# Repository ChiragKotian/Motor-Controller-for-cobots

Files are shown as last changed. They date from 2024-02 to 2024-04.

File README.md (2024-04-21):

# Motor-Controller-for-cobots

## Check out presentation.pdf(https://github.com/ChiragKotian/Motor-Controller-for-cobots/blob/main/presentation.pdf) for complete details

### _NOTE_: The final circuit shown in the schematics doesn't contain any protection for the inductive nature of the motor. Be sure to implement them before using this circuit or else you might end-up damaging your controller. 

## Credits

_This project was entirely done by Chirag Kotian (https://github.com/ChiragKotian) as a 'Pre-internship assignment' for PrimaInnotech. If you want to use my work, you are free to do so; don't forget to mention my GitHub page: https://github.com/ChiragKotian._

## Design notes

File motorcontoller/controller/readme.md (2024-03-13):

https://www.integrasources.com/blog/bldc-motor-controller-design-principles/

A typical BLDC motor controller has a half-bridge or half-H bridge circuit. Unlike an H bridge, this circuit configuration has only two switches - one high-side and one low-side transistor.

Typically, a sinusoidal brushless motor controller circuit uses pulse-width modulation (PWM). It helps regulate the current injected into the rotor’s windings and run the commutation process more smoothly and efficiently. This applies especially to closed-loop controllers that get feedback on the output signal and adjust the input power by varying the duty cycle.

When designing a BLDC motor controller, engineers can use different current switching, including trapezoidal and sinusoidal commutation. The names relate to the signal waveforms. 

The trapezoidal commutation allows two windings out of three to stay energized simultaneously. In the sinusoidal approach, the phase shift complies with the law of sines, so current switching between the phases becomes smoother. 

((Cant do SPI as D10,D11 PWM) between hall and mcu use I2C

https://ams.com/documents/20143/36005/AS5147_DS000307_3-00.pdf)

Use other Mag encoder
ams AS5048B

magnetic encoder, no moving parts

- 0.02197 deg resolution
- 14 bit resolution

-In applications where a sensored FOC scheme is preferred, Infineon’s XENSIV™ TLE5012 magnetic angle sensors with 0.01° resolution can be used 
for precise positioning. (SPI)

Compare with 



Similar Vdsmax and Ids max

80kHz



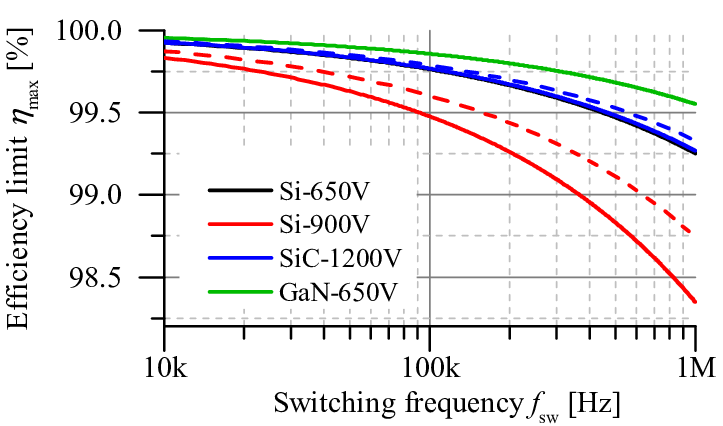
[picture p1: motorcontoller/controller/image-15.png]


We can use 200kHz similar switching loses

150% increase in frequency

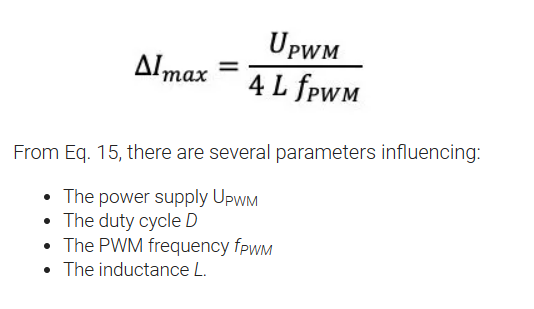
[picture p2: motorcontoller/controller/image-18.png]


60% reduction in ripple currrent

https://www.controleng.com/articles/understanding-the-effect-of-pwm-when-controlling-a-brushless-dc-motor/

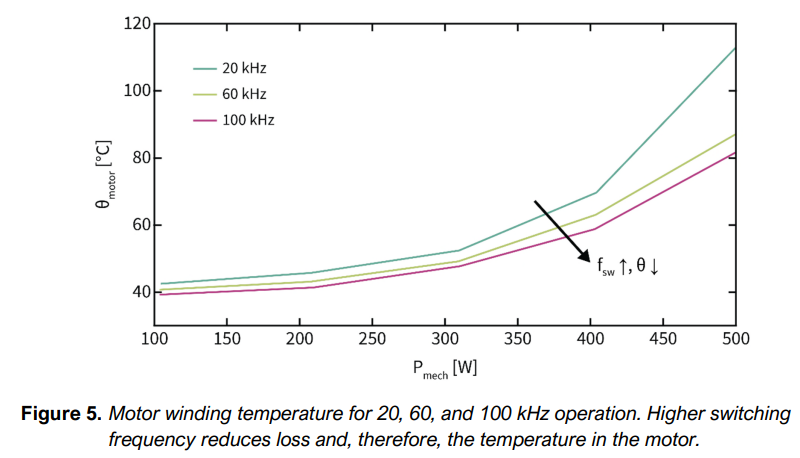
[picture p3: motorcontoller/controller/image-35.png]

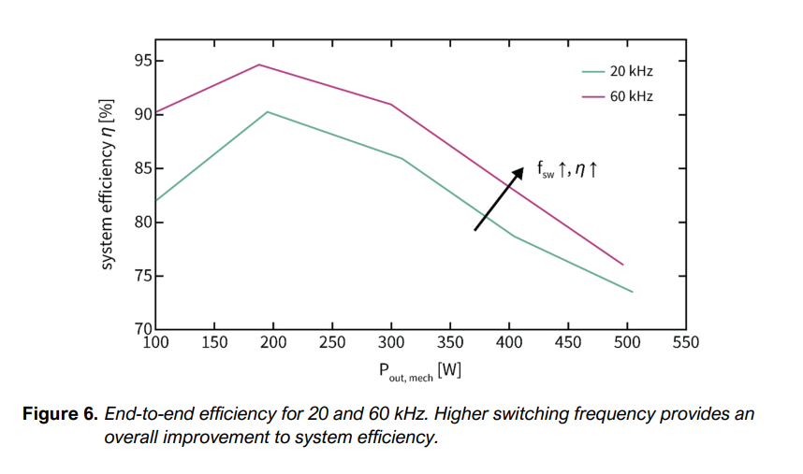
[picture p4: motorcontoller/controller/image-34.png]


Maerz, Martin & Heckel, Thomas & Rettner, Cornelius. (2015). Fundamental Efficiency Limits in Power Electronic Systems. 10.1109/INTLEC.2015.7572399. 

4 GaNs

-IGO60R070D1 
-IGOT60R070D1 
-IGLD60R070D1 
-IGT60R070D1 

we will use IGT60R070D1

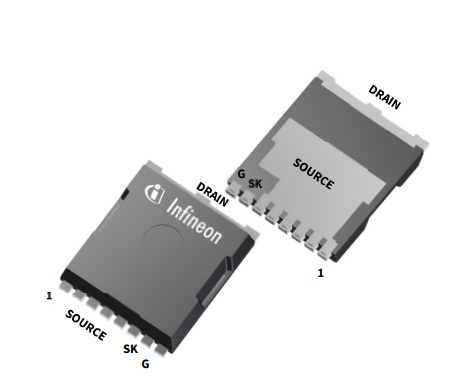
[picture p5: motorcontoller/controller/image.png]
![alt text](image-1.png)


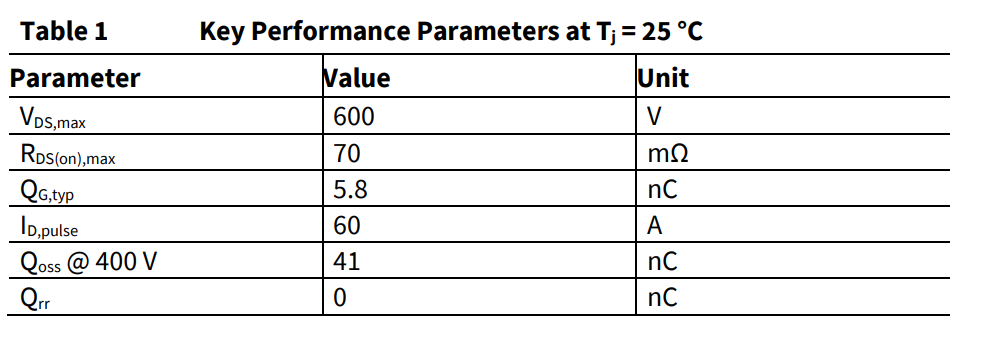
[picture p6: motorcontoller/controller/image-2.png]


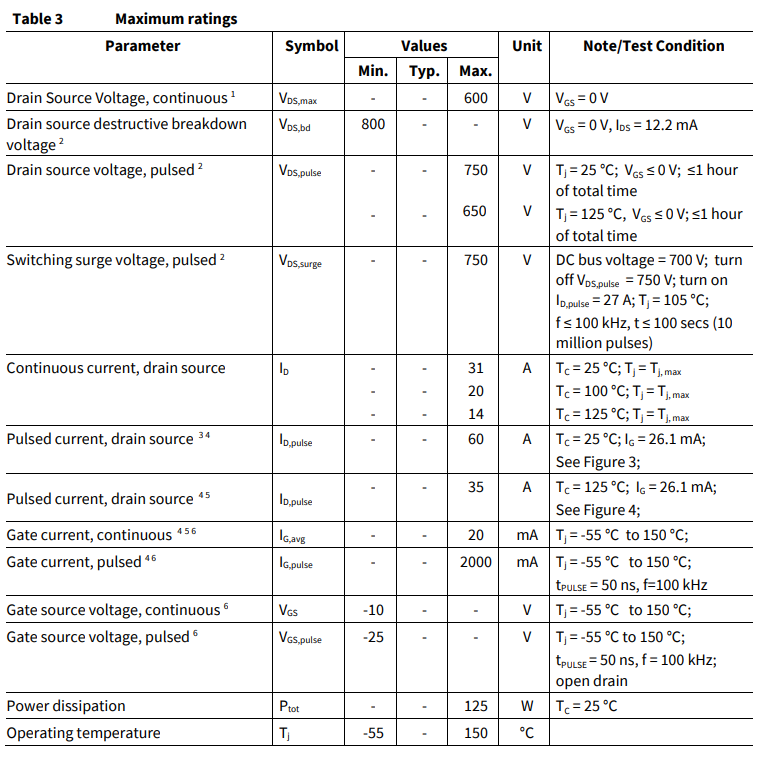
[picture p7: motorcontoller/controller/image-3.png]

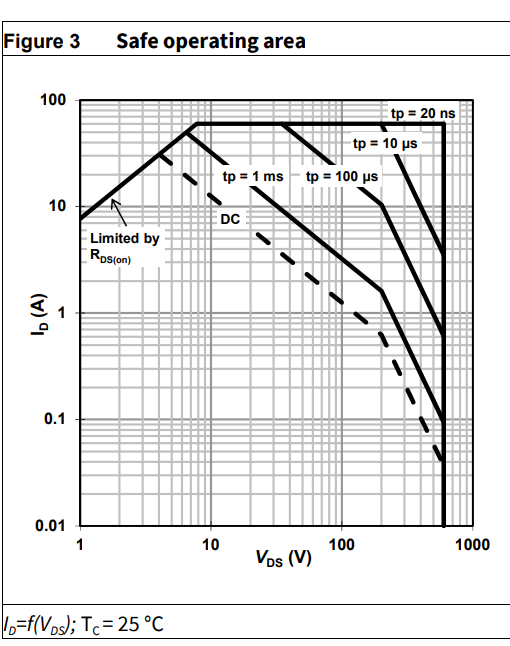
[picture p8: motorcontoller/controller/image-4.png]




Vgs = 5

turn on delay = 10ns
turn off delay = 14ns

GaN driver-
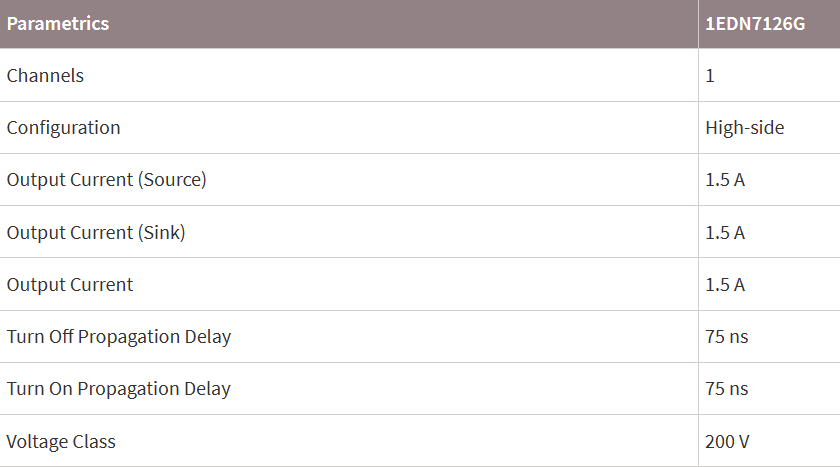
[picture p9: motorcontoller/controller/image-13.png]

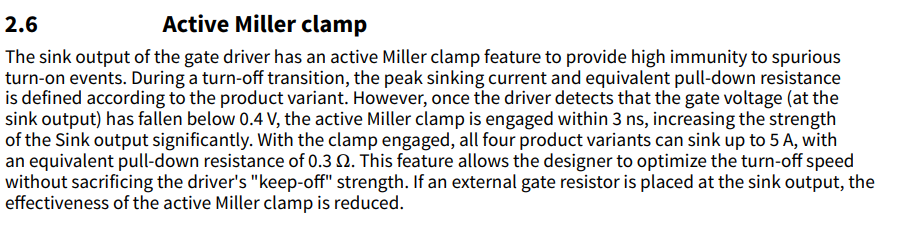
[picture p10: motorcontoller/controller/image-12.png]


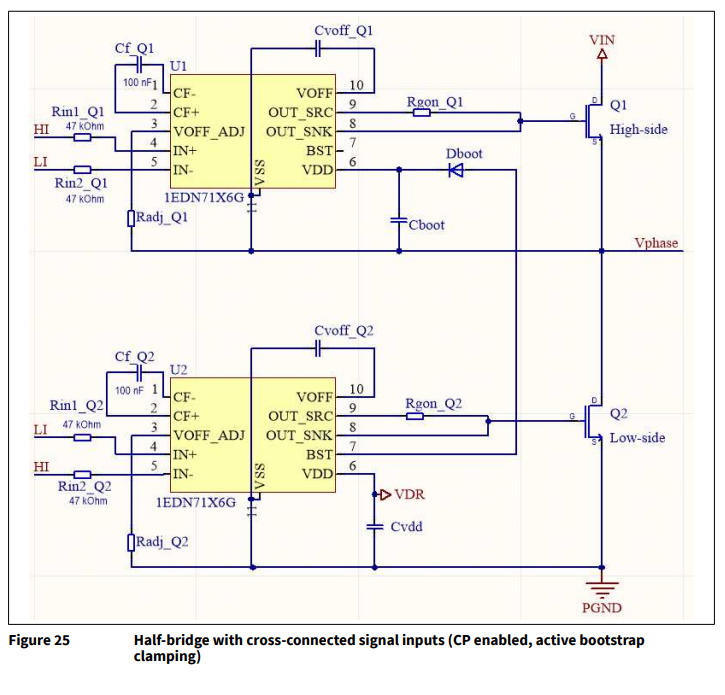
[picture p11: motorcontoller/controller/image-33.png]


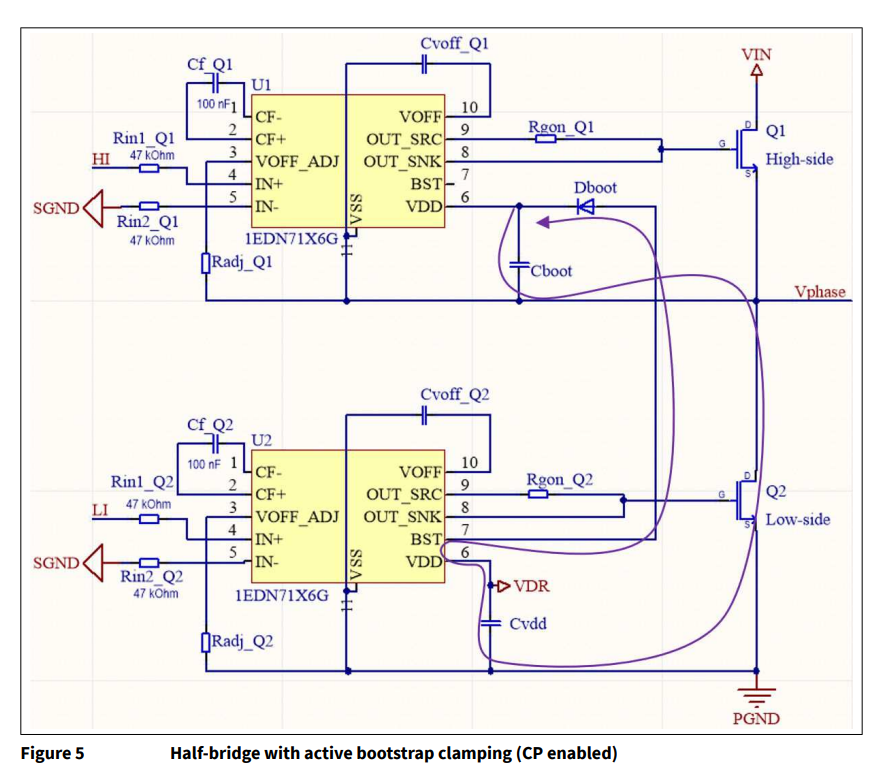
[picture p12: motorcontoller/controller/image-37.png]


Turn on, off  propagation delay= 75ns
impulse blanking time = 40ns(min time pulse on)

A gate driver is a power amplifier that accepts a low power input from a controller IC and produces the appropriate high current gate drive for a power device. It is used when a PWM controller cannot provide the output current required to drive the gate capacitance of the associated power device.

In motor drive applications, such as those used for robotics, drones, automotive, and industrial machinery, high switching frequencies enable higher power density, increased efficiency, higher performance, and reduced EMI. These benefits can make GaN-based motor drive systems more compact, reliable, and cost-effective than silicon-based systems.

Max frequency= 1/((10+14+75+75+40)*10^-9) = 4.673MHz

unoR4 minima: 48Mhz
9 bit resolution -> 93.75kHz
~8 bit resolution -> 200kHz (240)
voltage control resolution= 0.234375V @60V and 0.15625V @ 40V
PI or PID
PWM: D3,D5,D6,D9,D10,D11
Analog: A0,A1,A2,A3,A4,A5 (Temp, Vref)
OverCurr: D2,D4,D7
Can use Analog Mux: SN74HC4851  8channel (D8,D12,D13)

STM32G491RE ARM Microcontroller 170MHz 850(more than 9 bits accuracy)

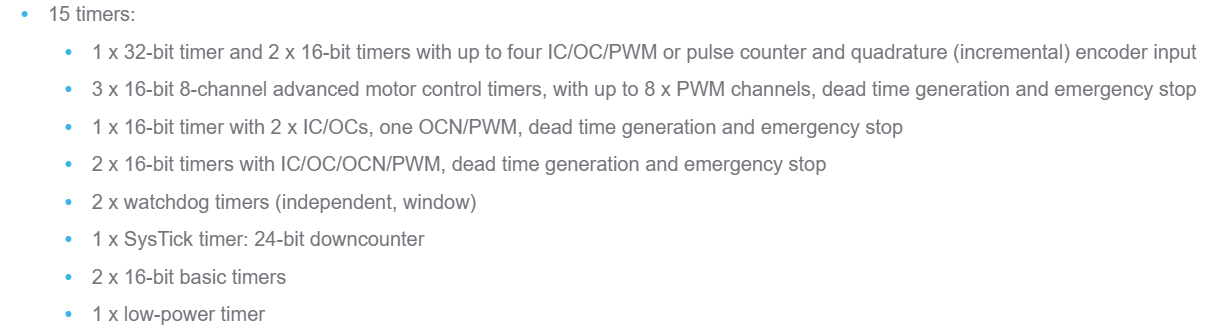
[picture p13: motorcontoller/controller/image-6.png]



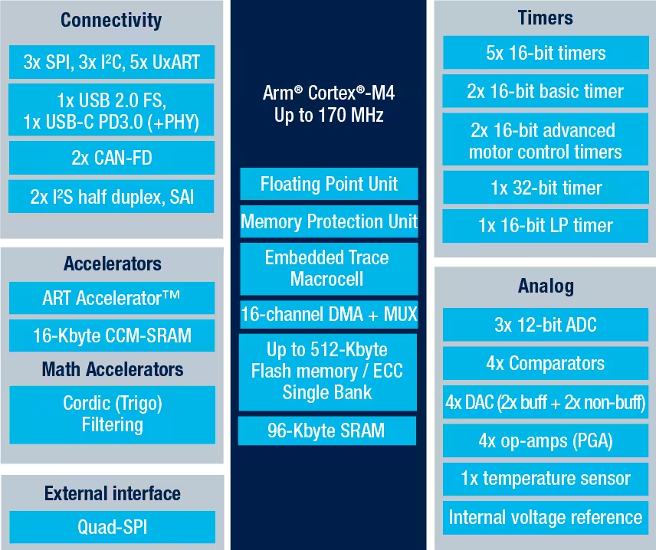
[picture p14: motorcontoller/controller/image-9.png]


or XMC4800-F100K2048 AA 144MHz 720 (more than 9 bit accuracy)
https://www.infineon.com/cms/en/product/microcontroller/32-bit-industrial-microcontroller-based-on-arm-cortex-m/32-bit-xmc4000-industrial-microcontroller-arm-cortex-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
(recommended for GaN and gate driver)
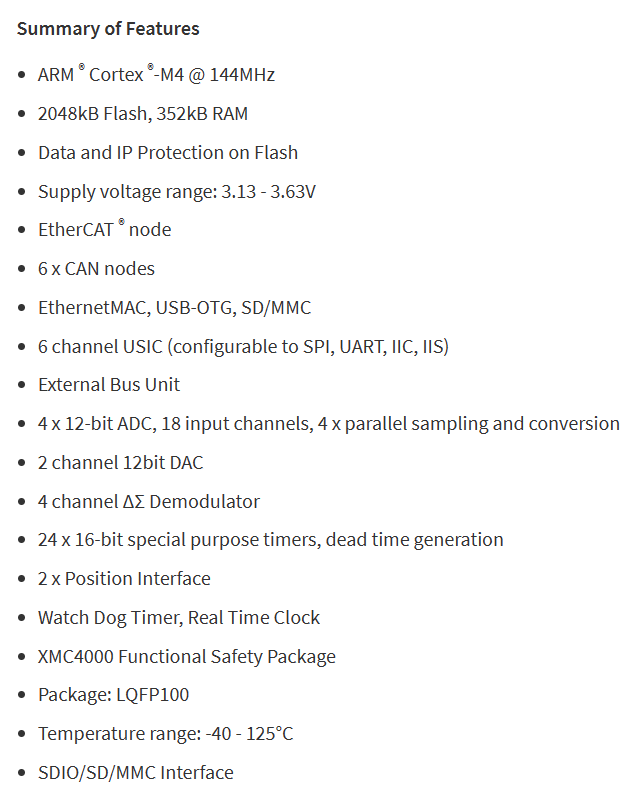
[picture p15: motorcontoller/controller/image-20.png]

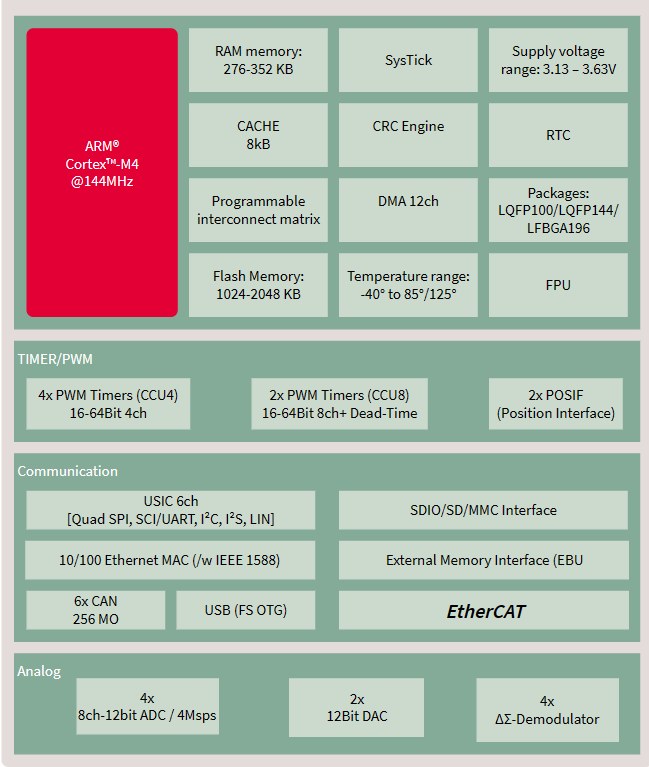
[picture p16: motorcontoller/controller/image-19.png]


The control was implemented using an XMC4400 drive card, using sensorless field-oriented control (FOC) firmware with a maximum switching frequency of 100 kHz and a control loop update rate of 
20 kHz. Increasing the control frequency to match the switching frequency at 100 kHz would enable even higher control bandwidth for applications that benefit from an extremely fast dynamic control response.

or AURIX 
https://www.infineon.com/cms/en/product/microcontroller/32-bit-tricore-microcontroller/

or PSOC
https://www.infineon.com/cms/en/product/microcontroller/32-bit-psoc-arm-cortex-microcontroller/

input 48 to 60V min. 40V
motor min voltage: 13.6V
motor max voltage: 21V
4-5s

19/40=0.475, 19/60=0.3167

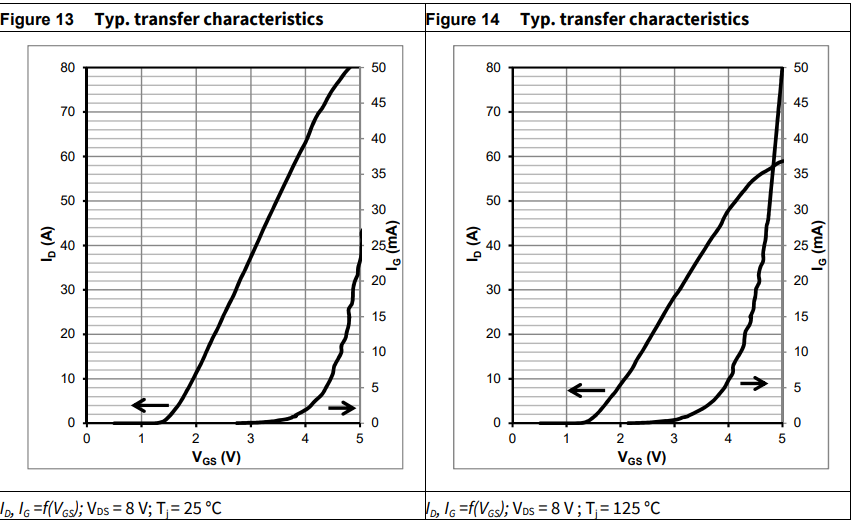
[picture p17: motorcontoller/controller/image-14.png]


max Ig= 10mA

off the shelf code:

very good open source project using field oriented control:
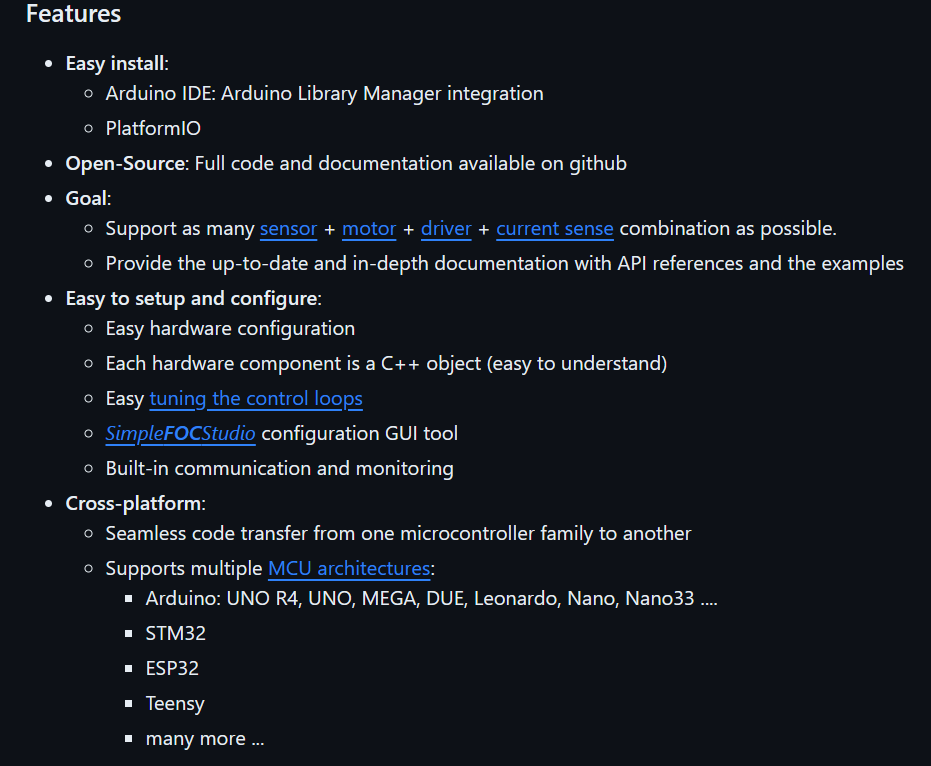
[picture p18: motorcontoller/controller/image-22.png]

https://github.com/simplefoc/Arduino-FOC
https://www.youtube.com/watch?v=Y5kLeqTc6Zk
https://www.youtube.com/watch?v=zSdetJsSeNw
https://www.youtube.com/watch?v=Nhy6g9wGHow

nice animation:
https://www.youtube.com/watch?v=YPD1_rcXBIE
 
good: normal motor trap control or sine control
https://github.com/byDagor/Janus-Controller

https://github.com/maakbaas/mbldc

https://github.com/qwertpas/O32controller

https://www.youtube.com/watch?v=VdkloigaxZo

https://github.com/SheffieldEcoMotorsports/motor-controller (with pid)

ref:
https://simple-circuit.com/arduino-sensorless-bldc-motor-controller-esc/

https://www.instructables.com/BLDC-Motor-Control-with-Arduino-salvaged-HD-motor/

https://simple-circuit.com/arduino-sensorless-brushless-motor-bldc/

https://simple-circuit.com/arduino-bldc-brushless-dc-motor-control/

circuit:

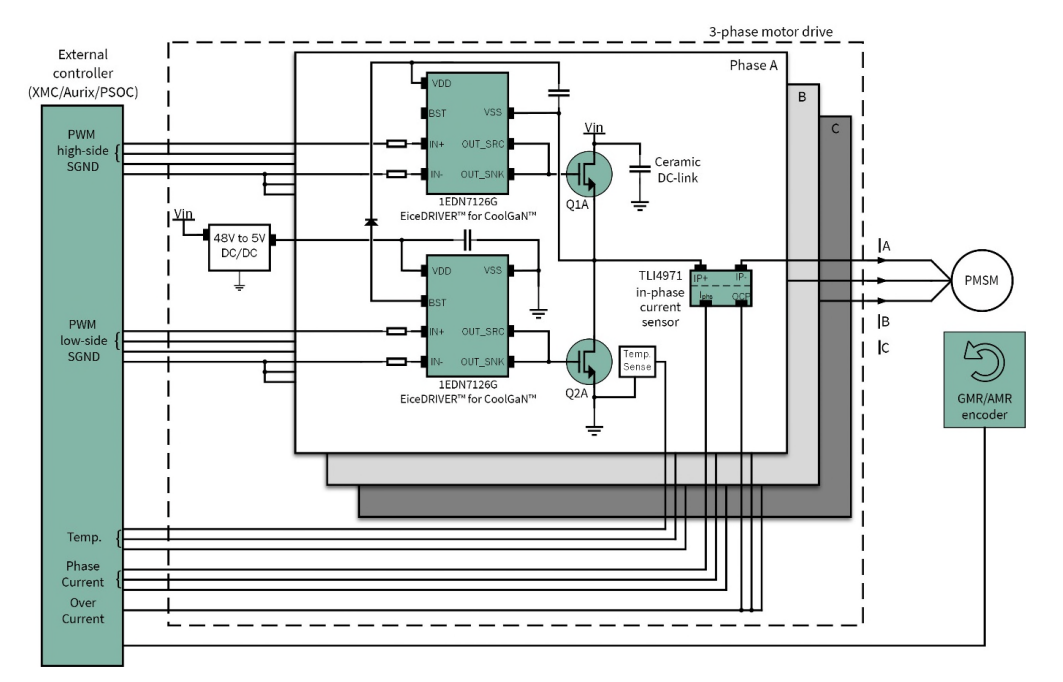
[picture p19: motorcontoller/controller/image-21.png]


theory:

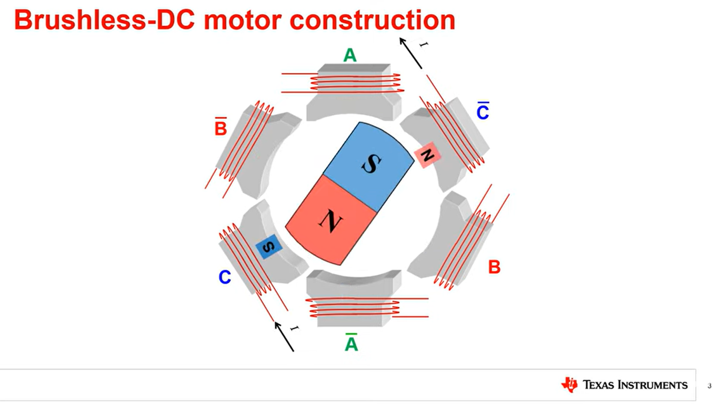
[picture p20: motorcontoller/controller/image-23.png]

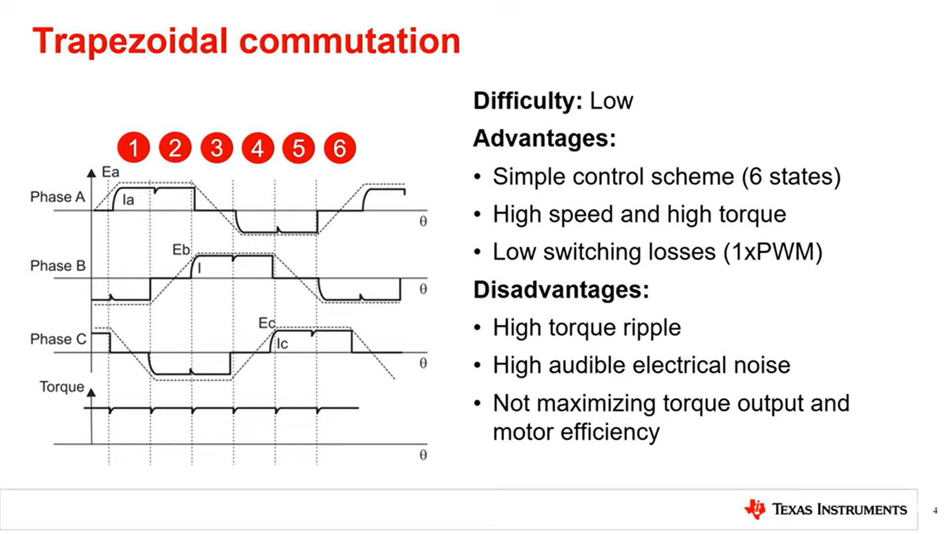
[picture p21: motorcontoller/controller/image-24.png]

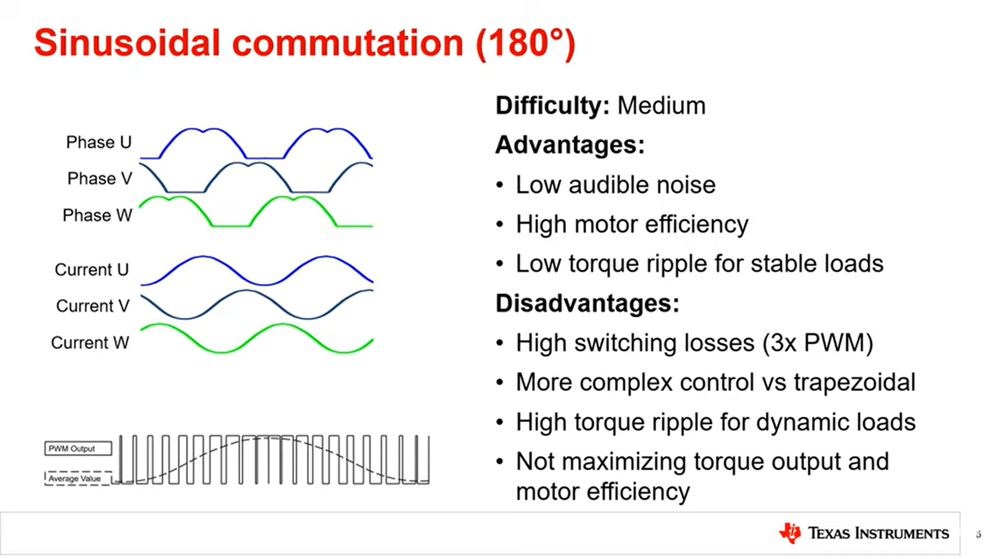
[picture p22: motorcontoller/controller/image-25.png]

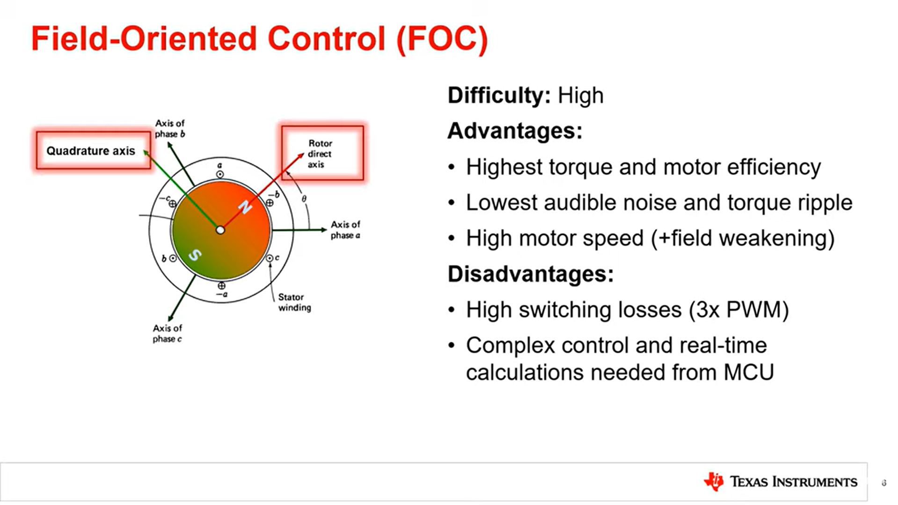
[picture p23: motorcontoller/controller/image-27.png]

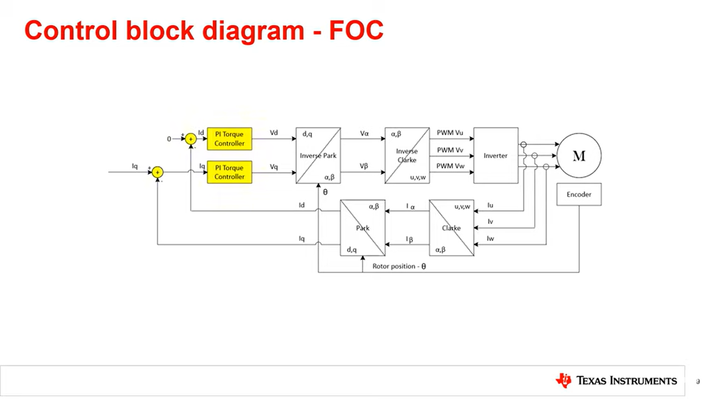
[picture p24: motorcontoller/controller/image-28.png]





https://www.youtube.com/watch?v=_6-_jvZe7iA

for buck convertor: 7V, can use LM5117

Current sensor:
The XENSIV™ TLI4971 Hall effect sensor avoids potential common-mode transient immunity (CMTI) issues with differential amplifiers. A well-isolated in-phase 
current sensor is more immune to voltage transients and provides accurate readings for field-oriented control of the motor. 

temp sens: TMP236 ±2.0°C analog output temperature sensor, with 19.5mV/°C gain

current sensor: TLI4971



Schematic:



BOM:



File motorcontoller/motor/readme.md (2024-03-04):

Motor specs:

In a brushless motor, the parameters you listed play crucial roles in determining its performance, characteristics, and behavior. Here's a brief explanation of each parameter and how they impact the motor:

1. **Poles**: Poles refer to the number of magnetic poles in the motor. The number of poles affects the motor's speed-torque characteristics and its maximum speed.

2. **V/Hz**: This parameter refers to the voltage-to-frequency ratio and is related to the motor's control method, particularly in variable frequency drives (VFDs). It determines the ratio at which voltage and frequency should be adjusted to control the motor's speed and torque effectively.

3. **Resistance (ohm)**: Resistance represents the opposition to the flow of current in the motor windings. Higher resistance leads to more heat generation and power loss but can provide better control over the motor's behavior.

4. **Kv (rpm/V)**: Kv, or the motor velocity constant, represents the motor's speed constant. It indicates how many revolutions per minute (rpm) the motor will turn for each volt applied to it. Kv is an essential parameter for understanding the motor's speed-torque relationship.

5. **Inductance (uH)**: Inductance represents the motor winding's ability to store energy in the form of a magnetic field. It impacts the motor's electrical time constants, affecting its response to changes in current and speed.

6. **Torque constant (Nm/A)**: The torque constant relates the motor's torque output to the current flowing through its windings. It determines how much torque the motor will produce for a given amount of current.

7. **Rated current (A)**: Rated current is the maximum continuous current that the motor windings can handle without causing overheating or damaging the motor.

8. **Rated voltage (V)**: Rated voltage is the nominal voltage at which the motor is designed to operate efficiently.

9. **Rated power (W)**: Rated power is the maximum continuous mechanical power output of the motor under normal operating conditions.

10. **Rated speed (rpm)**: Rated speed is the maximum speed at which the motor can operate continuously without exceeding its design limitations.

11. **Desired torque (Nm)**: Desired torque is the torque level that the motor needs to produce to meet the requirements of a specific application.

12. **Operating current (A)**: Operating current is the actual current flowing through the motor during operation, which can vary based on the load and operating conditions.

13. **Operating speed (rpm)**: Operating speed is the actual speed at which the motor operates under given conditions.

14. **Operating power (W)**: Operating power is the mechanical power output of the motor under specific operating conditions.

15. **Coil reactance (ohm)**: Coil reactance represents the opposition to changes in current flow due to the magnetic field stored in the motor windings. It is related to the inductance and frequency of the motor's operation.

These parameters collectively define the performance, efficiency, and behavior of a brushless motor in various applications. Understanding and properly configuring these parameters are essential for optimizing motor performance and ensuring reliable operation.

Given specs:
4-5s
Parameter	          :  Model
Motor	              :  Turnigy Aerodrive SK3 -4240-740kv
Poles	              :  14
V/Hz	              :  0.045420136
Resistance (ohm)	  :  0.0151
Kv (rpm/V)	          :  660.5
Inductance (uH)	      :  11.85833333
Torque constant (Nm/A):	 0.011276989
Rated current (A)	  :  50
Rated voltage (V)	  :  19
Rated power (W)	      :  870
Rated speed (rpm)	  :  12549.5
Desired torque (Nm)	  :  0.3
Operating current  (A):	 26.60284548
Operating speed (rpm) :	 3000
Operating power (W)	  :  94.24777961
Coil reactance (ohm)  :	 0.003725405

What we want:

Motor RPM: 0-3000RPM
Gearbox  : 100:1
Torque   : 30Nm
Input    : 48-60V min.40V
Min. size and weight of power cables internal to the cobot

Calculations and imp params:

Output RPM          : 0-30RPM (Motor RPM/Gearbox)
Motor Torque        : 0.3Nm (Torque/Gearbox)
Current required    : 26.603A (Motor Torque/Torque constant)
Operating power(W)	: 94.24777961
_Control Hz required : (40)880.67Hz-(48)1056.8Hz-(60)1321Hz_**Don't consider**

Time Constant       : 7.85*10^-4 (Inductance/Resistance) -> 5times -> 0.003925
Resultant Freq      : 254.7Hz <-Large ripple

High PWM frequencies for non audible operation 20kHz and also high freq less ripple

For high efficiency always keep pwm far from 50% duty cycle

PWM higher than 50kHz and above 80kHz for motors with very small electrical time constant.

Increase inductance, reduces ripple, inductance varies depending on PWM freq. 

https://www.portescap.com/en/newsroom/whitepapers/2021/10/understanding-the-effect-of-pwm-when-controlling-a-brushless-dc-motor

**Use a PWM frequency as high as possible considering driver circuit limitations and switching losses** as ripple will be minimum

Determining the PWM (Pulse Width Modulation) frequency for a brushless motor involves considering several factors including motor characteristics, drive circuitry, and control requirements. While there isn't a single mathematical formula that universally determines the PWM frequency for all brushless motors, there are guidelines and considerations to help determine an appropriate PWM frequency.

Here are some general guidelines and factors to consider:

1. **Motor Characteristics**: The PWM frequency should be high enough to ensure smooth motor operation and minimize audible noise, especially at low speeds. However, it should not be excessively high to avoid increasing switching losses in the motor driver circuitry.

2. **Switching Losses**: Higher PWM frequencies result in increased switching losses in the motor drive circuitry, which can reduce overall efficiency and increase heat generation. Therefore, the PWM frequency should strike a balance between minimizing switching losses and ensuring smooth motor operation.

3. **Control System Requirements**: The PWM frequency should be compatible with the control system's sampling rate and response time requirements. Choosing a PWM frequency that aligns with the control system's dynamics can help optimize motor performance and response.

4. **Drive Circuitry**: The drive circuitry, including the motor driver ICs and power transistors, may have recommended or maximum PWM frequency specifications. It's important to ensure that the selected PWM frequency is within the limits specified by the drive circuitry to prevent damage and ensure reliable operation.

5. **Noise Considerations**: PWM frequency can affect electromagnetic interference (EMI) and audible noise produced by the motor and drive electronics. Selecting a PWM frequency that minimizes EMI and audible noise interference is important, especially in applications where electromagnetic compatibility (EMC) is critical.

6. **Application Requirements**: Consider the specific requirements and constraints of the application, such as speed range, torque control, and dynamic response. The PWM frequency should be selected to meet the performance and efficiency requirements of the application.

As for a mathematical formula, there isn't a single formula to determine the PWM frequency for all brushless motors due to the variability in motor characteristics and application requirements. Instead, the PWM frequency is typically determined through experimentation, simulation, or reference to motor driver datasheets and application notes.

Datasheets for motor drivers and control ICs often provide recommendations and guidelines for selecting an appropriate PWM frequency based on the specific characteristics of the motor and drive circuitry.

To determine the PWM frequency, you may consider starting with a moderate frequency (e.g., a few kHz) and then adjusting it based on performance, efficiency, and noise considerations specific to your application and motor system.

Therefore, while I can't provide a specific mathematical formula, the determination of the PWM frequency involves a consideration of various factors and may require iterative experimentation and optimization based on the specific requirements and constraints of your application.

Certainly! While there isn't a universally applicable formula for determining the PWM frequency of brushless motors, there are some approximate guidelines you can use to determine a starting point for your PWM frequency selection:

1. **Switching Losses and Efficiency**: 
   - As a general guideline, PWM frequencies in the range of a few kHz to tens of kHz are commonly used for brushless motor control applications.
   - Higher frequencies typically result in lower switching losses but may increase electromagnetic interference (EMI) and audible noise.
   - Lower frequencies reduce EMI and audible noise but may increase switching losses and reduce efficiency.

2. **Electromagnetic Interference (EMI)**:
   - For applications sensitive to EMI, consider starting with PWM frequencies in the lower range (e.g., 10 kHz or lower) and adjust as necessary to minimize EMI interference.

3. **Audible Noise**:
   - Audible noise from motor and drive electronics can be minimized by selecting PWM frequencies above the audible range (20 kHz and higher).

4. **Drive Circuitry Recommendations**:
   - Check the datasheets and application notes provided by the motor driver and control IC manufacturers for recommended PWM frequency ranges.
   - Some motor driver ICs may have maximum or recommended PWM frequency specifications that you should adhere to.

5. **Motor Dynamics**:
   - Consider the speed range and dynamic response requirements of your application.
   - Higher PWM frequencies can provide better dynamic response and smoother operation, especially at lower speeds.

6. **Thermal Considerations**:
   - Consider the thermal characteristics of your motor and drive circuitry.
   - Higher PWM frequencies may result in increased heat generation in the drive circuitry, so ensure that the components can handle the thermal load.

Based on these considerations, you can start with a PWM frequency in the range of a few kHz to tens of kHz and then adjust based on performance, efficiency, and noise considerations specific to your application.

For example, a starting point could be a PWM frequency of 10 kHz, and then you can adjust it higher or lower based on your specific requirements and constraints.

Remember that the optimal PWM frequency may vary depending on your application and system requirements, so it's essential to experiment and evaluate the performance of different PWM frequencies to find the most suitable one for your application.

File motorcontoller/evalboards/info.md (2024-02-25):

Evaluation boards for motor controllers are hardware platforms designed to facilitate the testing, evaluation, and development of motor control systems. These boards typically include:

1. **Motor Driver Circuitry**: The evaluation board integrates the motor driver circuitry, which consists of power electronics (such as MOSFETs or IGBTs) capable of driving the motor with the required voltage and current levels.

2. **Microcontroller or Digital Signal Processor (DSP)**: A microcontroller or DSP is often included on the evaluation board to provide the necessary processing power for motor control algorithms, communication interfaces, and system supervision.

3. **Interfaces**: Evaluation boards typically feature various interfaces such as USB, UART, SPI, I2C, or CAN, enabling communication with external devices like computers, microcontrollers, or other control systems. These interfaces facilitate configuration, monitoring, and control of the motor controller.

4. **Sensors**: Many evaluation boards come with sensor inputs (such as encoders, hall effect sensors, or current sensors) that allow the motor controller to gather feedback about the motor's position, speed, and current. This feedback information is crucial for implementing closed-loop control algorithms like PID (Proportional-Integral-Derivative) control.

5. **Power Supply Circuitry**: To power both the motor and the control electronics, the evaluation board may include power supply circuitry with appropriate voltage and current ratings.

6. **Development Software**: Evaluation boards often come with development software tools that provide graphical user interfaces (GUIs), APIs, or libraries for configuring the motor controller, tuning control parameters, monitoring performance, and debugging.

7. **Documentation and Support**: Manufacturers typically provide documentation such as datasheets, user manuals, application notes, and example code to help users understand the features and functionalities of the evaluation board and to assist them in the development process.

Overall, evaluation boards for motor controllers serve as valuable tools for engineers and developers to quickly prototype, evaluate, and develop motor control systems for various applications such as robotics, industrial automation, electric vehicles, and consumer electronics.

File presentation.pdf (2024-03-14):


# M otor c o n t r o l l e r

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

# Introduction


## Our aim is design, build, and test a compact

## controller for a brushless DC (BLDC) motor suitable

## for driving the joint of a cobot

### - Theory

### - Research

### - Implementation

### - Further works

Motor Controller for a BLDC motor | 2

# Theory

Let’s first have a look at Brushless Motor, types of commutation and controlling BLDC motors

### and why GaNs. We will also see what is switching losses and how to minimize them in GaNs

section.

Brushless Motor | Types of
Commutation | Why GaNs

# Few Types of Motors


# Brushless Motor


# Three Phase H-Bridge Inverter

# Position Feedback


# Motor Params

Given specs: 4-5s (13.6V - 21V) Motor : Turnigy Aerodrive SK3 -4240-740kv Poles : 14 V/Hz : 0.045420136 Resistance (ohm) : 0.0151 Kv (rpm/V) : 660.5 Inductance (uH) : 11.85833333 Torque constant (Nm/A): 0.011276989 Rated current (A) : 50 Desired torque (Nm) : 0.3 Operating current (A): 26.60284548 Operating speed (rpm) : 3000 Operating power (W) : 94.24777961 Coil reactance (ohm) : 0.003725405 What we want:


Motor RPM: 0-3000RPM Gearbox : 100:1 Torque : 30Nm Input : 48-60V min.40V Min. size and weight of power

## cables internal to the cobot

# Trapezoidal commutation

9

Motor Controller for a BLDC motor

## Used widely in brushless motor ESCs

# Sinosoidal commutation


# Field Oriented Control(FOC)


# Field Oriented Control(FOC)

# How to implement PID/PI control loop


# Calculations and Controls in Field Oriented Control(FOC)

# Why GaNs: PWM and frequency

## PWM used for current and voltage control (Duty cycle)


# Why GaNFETs: PWM and frequency

Determining the PWM (Pulse Width Modulation) frequency for a brushless motor involves considering several factors including motor characteristics, drive circuitry, and control requirements.
1.Motor Characteristics: The PWM frequency should be high enough to ensure smooth motor operation and minimize audible noise, especially at low speeds. However, it should not be excessively high to avoid increasing switching losses in the motor driver circuitry.
2.Switching Losses: Higher PWM frequencies result in increased switching losses in the motor drive circuitry, which can reduce overall efficiency and increase heat generation. Therefore, the PWM frequency should strike a balance between minimizing switching losses and ensuring smooth motor operation.
3.Control System Requirements: The PWM frequency should be compatible with the control system's sampling rate and response time requirements. Choosing a PWM frequency that aligns with the control system's dynamics can help optimize motor performance and response. 4.Drive Circuitry: The drive circuitry, including the motor driver ICs and power transistors, may have recommended or maximum PWM frequency specifications. It's important to ensure that the selected PWM frequency is within the limits specified by the drive circuitry to prevent damage and ensure reliable operation.
5.Noise Considerations: PWM frequency can affect electromagnetic interference (EMI) and audible noise produced by the motor and drive electronics. Selecting a PWM frequency that minimizes EMI and audible noise interference is important, especially in applications where electromagnetic compatibility (EMC) is critical.
6.Application Requirements: Consider the specific requirements and constraints of the application, such as speed range, torque control, and dynamic response. The PWM frequency should be selected to meet the performance and efficiency requirements of the application.

## In normal ESCs, with SiC MOSFETs, PWM frequency of 50-80kHz is used

# Why GaNFETs: PWM and frequency

## In normal ESCs, with SiC MOSFETs, PWM frequency of 80kHz is used


## - We can use 200kHz PWM frequency for similar switching loses using GaNs instead of commonly used SiC (An SiC MOSFET e.g. is attached at the bottom with characteristics similar to selected GaNFET) - 150% increase in frequency - 60% reduction in ripple currrent

# Why GaNs: PWM and frequency


## - PWM Duty Cycle: - MAX: 19/40=0.475 (47.5% @ Min Voltage) - MIN: 19/60=0.3167 (31.7% @ Max Voltage)

# Selected GaNFET

## Options Infineon Provided:

## - 4 GaNs: -IGO60R070D1 -IGOT60R070D1 -IGLD60R070D1 -IGT60R070D1

## (All have the similar Electrical Characteristics, just footprints are different)

## - We will be using IGT60R070D1


## Max Frequency supported: 41.67 MHz

# Recommended Circuit by Infineon


## - Recommended GaNFET driver: - 1EDN7126G (EiceDriver for CoolGaN) - Recommended Current sensor: - TLI4971 - Recommended MCUs or Controllers: - XMC - Aurix - PSOC - Recommended encoder - GMR - AMR

# GaNFET driver

## - Recommended GaNFET driver - 1EDN7126G (EiceDriver for CoolGaN)

## What is Gate Driver?

- A gate driver is a power amplifier that accepts a low power input from a controller IC and produces the appropriate high current gate drive for a power device. It is used when a PWM controller cannot provide the output current required to drive the gate capacitance of the associated power device.
- This driver along with GaNFETs can be used in motor drive applications, such as those used for robotics, drones, automotive, and industrial machinery where high switching frequencies enable higher power density, increased efficiency, higher performance, and reduced EMI. These benefits can make GaN-based motor drive systems more compact, reliable, and cost-effective than silicon-based systems.

## - Turn on, off propagation delay= 75ns impulse blanking time = 40ns(min time pulse on) - Max frequency= 1/((10+14+75+75+40)*10^-9) = 4.673MHz

# GaNFET driver


# Current Sensor

- The XENSIV TLI4971 Hall effect sensor avoids potential common-mode transient immunity (CMTI) issues with differential amplifiers. A well-isolated in-phase current sensor is more immune to voltage transients and provides accurate readings for field-oriented control of the motor.

# MCU

## - XMC4800-F100K2048 AA 144MHz


## - More than 9bits of PWM accuracy

# Alternative MCU

## - STM32G491RE ARM Microcontroller 170MHz, more than 9bits of PWM accuracy (Even more than


## XMC4800-F100K2048)

# Encoder

## - Recommended encoder: Infineon XENSIV TLE5012 magnetic angle sensors with 0.01° resolution - In applications where a sensored FOC scheme is preferred, this encoder can be used

for precise positioning.

## - Uses SPI protocol

## - Used Magnetic encoder: ams AS5048B - Used this because of SPI pin limitation on Arduino(PWM+SPI pin) - Magnetic encoder, no moving parts •0.02197 deg resolution •14 bit resolution •Used I2C protocol

# MCU board to be used for testing and Additional Component Details


## - For buck convertor: 7.5V, we can use LM5117 - For temperature sensor: TMP236

- ±2.0°C analog output temperature sensor,

## with 19.5mV/°C gain


## - Arduino unoR4 minima: - 48Mhz Clock speed - 8 bit resolution -> 200kHz (240) - voltage control resolution= 0.234375V @60V and 0.15625V @ 40V - PWM: D3,D5,D6,D9,D10,D11 - A/D C: A0,A1,A2,A3,A4,A5 (Used by Temperature, Vref, Current) - OverCurr: D2,D4,D7

## - Analog Mux: SN74HC4851 8channel (D8,D12,D13)


# Circuit Schematic


Motor Controller for a BLDC motor | • Made using open-source KiCAD | 29

# Bill of Materials

# Open-source FOC library with many features


## - SimpleFOC - https://simplefoc.com/


# Next Steps

## Completing the schematic

Simulation,

## Improvement, PCB designing

## Assembly and Testing

# Reference Links

- https://www.portescap.com/en/newsroom/whitepapers/2021/10/understanding-the-effect-of-pwm-when-controlling-a-brushless-dc-motor
- https://www.portescap.com/en/newsroom/whitepapers/2021/10/understanding-the-effect-of-pwm-when-controlling-a-brushless-dc-motor (https://www.portescap.com/en/newsroom/whitepapers/2021/10/understanding-the-effect-of-pwm-when-controlling-a-brushless-dc-motor)
- https://ams.com/documents/20143/36005/AS5147_DS000307_3-00.pdf
- https://www.controleng.com/articles/understanding-the-effect-of-pwm-when-controlling-a-brushless-dc-motor/
- https://www.infineon.com/cms/en/product/microcontroller/32-bit-industrial-microcontroller-based-on-arm-cortex-m/32-bit-xmc4000-industrial-microcontroller-arm-cortex-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 (https://www.infineon.com/cms/en/product/microcontroller/32-bit-industrial-microcontroller-based-on-arm-cortex-m/32-bit-xmc4000-industrial-microcontroller-arm-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)
- https://www.infineon.com/cms/en/product/microcontroller/32-bit-tricore-microcontroller/
- https://www.infineon.com/cms/en/product/microcontroller/32-bit-psoc-arm-cortex-microcontroller/
- https://github.com/simplefoc/Arduino-FOC
- https://www.youtube.com/watch?v=Y5kLeqTc6Zk
- https://www.youtube.com/watch?v=zSdetJsSeNw
- https://www.youtube.com/watch?v=Nhy6g9wGHow
- https://www.youtube.com/watch?v=YPD1_rcXBIE
- https://github.com/byDagor/Janus-Controller
- https://github.com/maakbaas/mbldc
- https://github.com/qwertpas/O32controller
- https://www.youtube.com/watch?v=VdkloigaxZo
- https://github.com/SheffieldEcoMotorsports/motor-controller
- https://simple-circuit.com/arduino-sensorless-bldc-motor-controller-esc/
- https://www.instructables.com/BLDC-Motor-Control-with-Arduino-salvaged-HD-motor/
- https://simple-circuit.com/arduino-sensorless-brushless-motor-bldc/
- https://simple-circuit.com/arduino-bldc-brushless-dc-motor-control/
- https://www.youtube.com/watch?v=_6-_jvZe7iA


# Thank you

### Chirag Kotian

+91 8591757109

### ee21b025@iittp.ac.in

### https://chiragkotian.github.io/

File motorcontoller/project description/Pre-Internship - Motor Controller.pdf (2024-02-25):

## Pre-Internship Assignments for the Brushless DC Motor Controller

The objective of the internship project is to design, build, and test a compact controller for a brushless DC (BLDC) motor suitable for driving the joint of a cobot. Two circuits must be developed: one for the motor controller (MC) and the other for the external power supply (PS).

MC: As a pre-internship assignment for the controller, the applicant will assess the suitability of a motor controller from one of the following suppliers (each of which will be assigned to an applicant): MJBots, EPC, Texas Instruments, Infineon, Navitas, and Renesas. The preference is to use controllers that use GaN HEMTs (rather than Si MOSFETs) to increase switching frequency, enhance electrical efficiency, avoid heat sinks, and shrink the footprint. These assessments will be used to determine how to mix and match controllers for a compact and low-cost controller that will be designed, built, and tested during the internship phase of the project.

Starting with the documentation in the appropriate folder within Resources:

- Review the specifications and operating conditions for a BLDC motor (Turnigy Aerodrive SK3 -4240-740kv) that are relevant for selecting the controller. This motor will be operated at 0 – 3000 rpm and will be connected to the joint of the cobot through a 100:1 reduction gearbox to achieve 30 Nm of torque at the joint. An input voltage of 48V – 60V (with a minimum of 40V) is desirable for each joint to minimize the size and weight of the power cables internal to the cobot.
- Survey and select an appropriate evaluation board or recommended circuit for driving the selected BLDC motor. For evaluation boards that can be configured with either GaN HEMTs or Si MOSFETs, determine how the board should be configured for GaN HEMTs.
- Select a rotary encoder (e.g. AS5147 from AMS or a variant such as AS5047) for providing motor position feedback to the controller and select the type of rotational feedback signal that is compatible with the controller.
- Select a microcontroller to interface with the evaluation board. Preferably select a microcontroller recommended for the evaluation board, or alternatively from Microchip, Texas Instruments, or ST Microelectronics. An Arduino or Raspberry Pi may be used for testing.
- Prepare a block diagram schematic showing the overall system that includes the BLDC motor, feedback sensor, evaluation board, microcontroller (if needed), external power supplies, and any additional components.
- Identify off-the-shelf or open-source code that is available or can be adapted to program the microcontroller, Arduino, or Raspberry Pi.
- Summarize the operation of the controller including its key circuit blocks and the description of signals (e.g. function, waveform (analog) or protocol (digital), voltage levels) between circuit blocks.
- Prepare a Bill-of-Material (BOM) for the test setup including estimated costs of components.
- Prepare and present the pre-internship assignment. A PowerPoint presentation is adequate.

PS: As a pre-internship assignment for the power supply, the applicant will assess the suitability of GaN HEMTs from one of the following suppliers (each of which will be assigned to an applicant): Texas Instruments, Infineon, Navitas, Power Integrations, and Transphorm. GaN HEMTs (rather than Si

MOSFETs) increase switching frequency, enhance electrical efficiency, avoid heat sinks, and shrink the footprint. These assessments will be used to determine how to mix and match components for a compact and low-cost power supply that will be designed, built, and tested during the internship phase of the project.

The power supply will use an input voltage of 110 VAC - 220 VAC and will output up to 20A at 48 VDC for ~1 kW of power which is sufficient to power all six joints and associated peripherals of the cobot. 48 VDC is a safe DC voltage for humans. It is a standard output voltage for telecom power supplies and is also being adopted as the new standard for AI servers and automotive electronics. Reference designs and evaluation boards are available from several suppliers.

Starting with the documentation in the appropriate sub-folder within Resources:

- Survey and select an appropriate evaluation board or recommended circuit for the power supply.
- If necessary, select a microcontroller to interface with the evaluation board or the circuit. Preferably select a microcontroller recommended for the evaluation board, or alternatively from Microchip, Texas Instruments, or ST Microelectronics. An Arduino or Raspberry Pi may be used for testing.
- Prepare a block diagram schematic showing the overall system that includes the evaluation board, microcontroller (if needed), feedback sensors (if needed), and any additional components.
- Identify off-the-shelf or open-source code that is available or can be adapted to program the microcontroller, Arduino, or Raspberry Pi.
- Summarize the operation of the power supply including its key circuit blocks and the description of signals (e.g. function, waveform (analog) or protocol (digital), voltage levels) between circuit blocks.
- Prepare a Bill-of-Material (BOM) for the test setup including estimated costs of components.
- Prepare and present the pre-internship assignment. A PowerPoint presentation is adequate.

Complete as much of the assignment as possible within the 4 week and 40-hour time limit. The documents should provide a starting point but use additional online resources as necessary.

It is possible that the assigned supplier does not have an evaluation board or reference circuit. If so, reference circuits provided by one of the other suppliers can be adapted for the GaN HEMTs from the assigned supplier. If suitable GaN HEMTs cannot be found, the assignment should be terminated with an explanation of the conclusions.

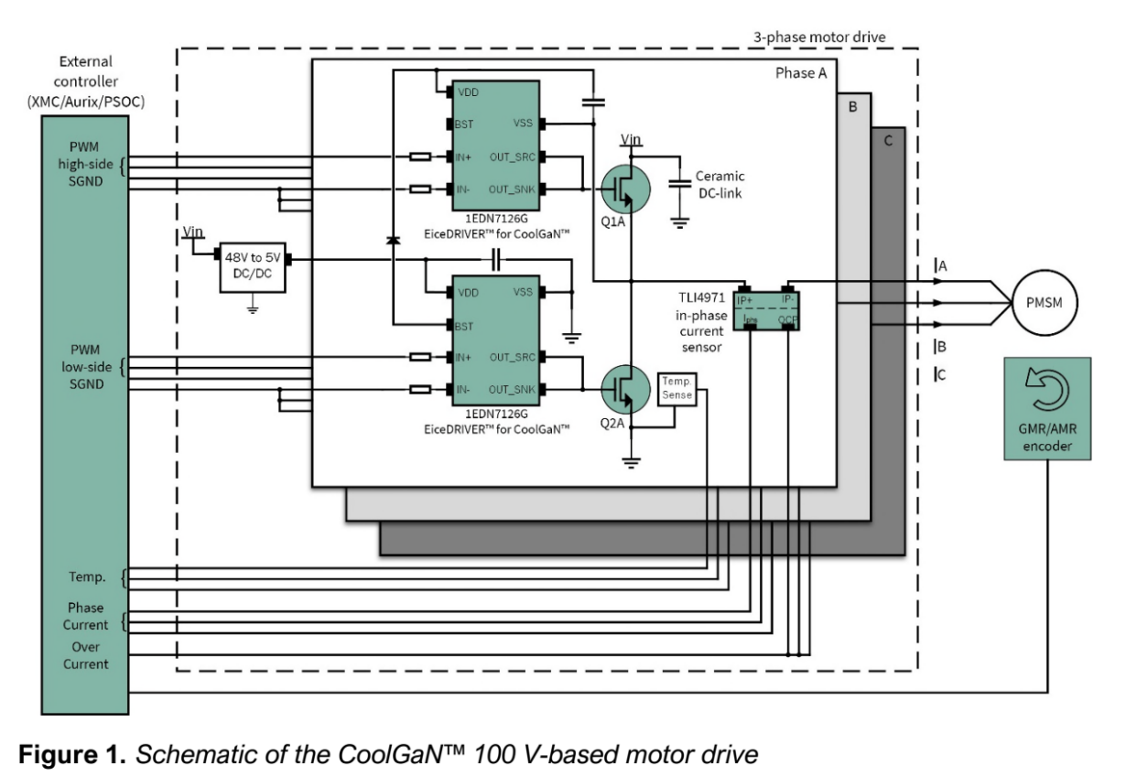
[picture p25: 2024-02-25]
motorcontoller/illustratons/Schematic of the CoolGan 100V based motor driver.png

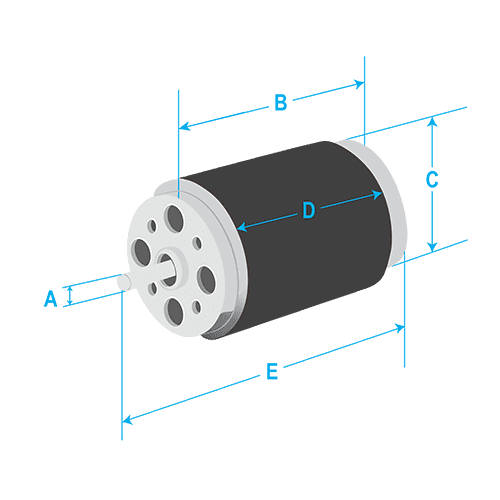
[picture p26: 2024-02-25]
motorcontoller/motor/turnigy sk3 4240 740kv.png

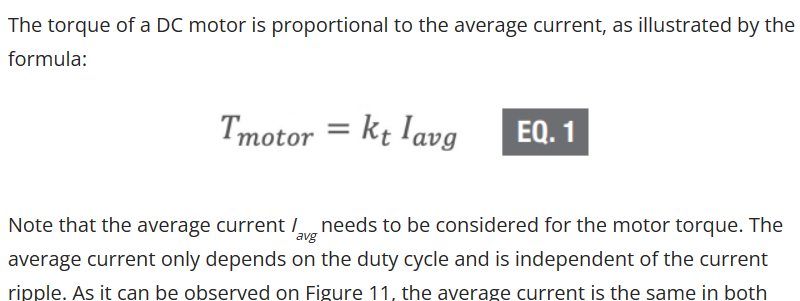
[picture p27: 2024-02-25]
motorcontoller/motor/Screenshot 2024-02-25 231355.png

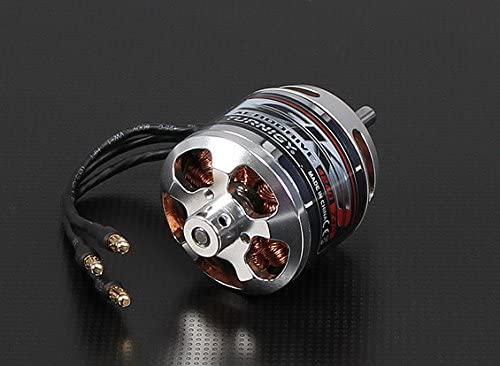
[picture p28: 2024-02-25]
motorcontoller/motor/Turnigy Aerodrive Illustration SK3 - 4240-740kv.jpg

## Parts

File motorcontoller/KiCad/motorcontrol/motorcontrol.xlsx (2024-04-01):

Source: | D:\PROJECTS\prima innotech\motorcontoller\KiCad\motorcontrol\motorcontrol.kicad_sch
Date: | 2024-03-13 09:52
Tool: | Eeschema 7.0.5
Generator: | E:\kicad\New folder\7.0\bin\scripting\plugins/bom_csv_grouped_by_value_with_fp.py
Component Count: | 86
Ref | Qnty | Value | Cmp name | Footprint | Description | Vendor | Rate | Cost | DNP
A1 | 1 | Arduino_Uno_R4_Minima_Shield | Arduino_Uno_R4_Minima | PCM_arduino-library:Arduino_Uno_R4_Minima | Arduino Uno R4 Minima which will be brain for the system | Robu | 1399 | 1399
C1, C2, C11, C12, C18, C23, C24 | 7 | 100 nF | C_Small |  | Unpolarized capacitor, small symbol | Electronics Comp | 2.2 | 15.4
C3, C4, C5, C6, C8, C13, C14, C16, C17, C20, C25, C26, C27, C28, C30 | 15 | C | C |  | Unpolarized capacitor | Electronics Comp | 2.2 | 33
C7, C19, C29 | 3 | 1 nF | C |  | Unpolarized capacitor | Electronics Comp | 2.2 | 6.6
C9, C21, C31 | 3 | 6.8 nF | C_Small |  | Unpolarized capacitor, small symbol | Electronics Comp | 2.2 | 6.6
C10, C22, C32 | 3 | 226.8 nF | C |  | Unpolarized capacitor | Electronics Comp | 4.4 | 13.2
C15 | 1 | 10 uH | C_Small |  | Unpolarized capacitor, small symbol | Electronics Comp | 2.2 | 2.2
D1, D2, D3 | 3 | 1N4007 | 1N4007 | Diode_THT:D_DO-41_SOD81_P10.16mm_Horizontal | 1000V 1A General Purpose Rectifier Diode, DO-41 | Electronics Comp | 1 | 3
IC1, IC2, IC6, IC7, IC10, IC11 | 6 | 1EDN7126GXTMA1 | 1EDN7126GXTMA1 | 1EDN7126GXTMA1 | Gate Drivers INT. POWERSTAGE/DRIVER | Mouser | 98.77 | 592.62
IC3, IC8, IC12 | 3 | TMP236AQDBZTQ1 | TMP236AQDBZTQ1 | SOT95P237X112-3N | Board Mount Temperature Sensors Automotive grade, &plusmn;0.5&deg;C analog output temperature sensor with 19.5 mV/&deg;C gain 3-SOT-23 -40 to 125 | Mouser | 67.81 | 203.43
IC4, IC9, IC13 | 3 | TLI4971A075T5UE0001XUMA1 | TLI4971A075T5UE0001XUMA1 | TLI4971A075T5UE0001XUMA1 | Infineon TLI4971A075T5UE0001XUMA1 | Mouser | 400.89 | 1202.67
IC5 | 1 | SN74HC4851DGVR | SN74HC4851DGVR | SOP40P640X120-16N | 8-Channel Analog Multiplexer/Demultiplexer with Injection-Current Effect Control | Mouser | 68.89 | 68.89
J1 | 1 | Screw_Terminal_For_Brushless_Motor | Screw_Terminal_01x03 |  | Generic screw terminal, single row, 01x03, script generated (kicad-library-utils/schlib/autogen/connector/) | Robu | 100 | 100
Q1, Q2, Q3, Q4, Q5, Q6 | 6 | IGT60R070D1 | IGT60R070D1 | Package_TO_SOT_SMD:Infineon_PG-HSOF-8-3_ThermalVias | 31A Id, 600V Vds, 70mOhm, N-Channel GaN MOSFET, HSOF-8 | Mouser | 955.33 | 5731.98
R1, R2, R3, R4, R8, R9, R10, R11, R12, R13, R14, R15, R16, R17, R18, R19, R23, R24, R25, R26 | 20 | R | R |  | Resistor | Electronics Comp | 2 | 40
R5, R20, R27 | 3 | 4.7 k | R |  | Resistor | Electronics Comp | 2 | 6
R6, R7, R21, R22, R28, R29 | 6 | 1 k | R |  | Resistor | Electronics Comp | 2 | 12
U1 | 1 | AS5048B | AS5048B | Package_SO:TSSOP-14_4.4x5mm_P0.65mm | Magnetic position sensor, 14-bit, PWM output, I2C Interface, TSSOP-14 | Mouser | 755.3 | 755.3
 |  |  |  |  |  |  | Total | 10191.89

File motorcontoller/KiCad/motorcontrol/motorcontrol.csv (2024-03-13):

Source: | D:\PROJECTS\prima innotech\motorcontoller\KiCad\motorcontrol\motorcontrol.kicad_sch
Date: | 13/03/2024 09:52:20
Tool: | Eeschema 7.0.5
Generator: | E:\kicad\New folder\7.0\bin\scripting\plugins/bom_csv_grouped_by_value_with_fp.py
Component Count: | 86
Ref | Qnty | Value | Cmp name | Footprint | Description | Vendor | DNP
A1 | 1 | Arduino_Uno_R4_Minima_Shield | Arduino_Uno_R4_Minima_Shield | PCM_arduino-library:Arduino_Uno_R4_Minima_Shield | Shield for Arduino Uno R4 Minima
C1, C2, C11, C12, C18, C23, C24 | 7 | 100 nF | C_Small |  | Unpolarized capacitor, small symbol
C3, C4, C5, C6, C8, C13, C14, C16, C17, C20, C25, C26, C27, C28, C30 | 15 | C | C |  | Unpolarized capacitor
C7, C19, C29 | 3 | 1 nF | C |  | Unpolarized capacitor
C9, C21, C31 | 3 | 6.8 nF | C_Small |  | Unpolarized capacitor, small symbol
C10, C22, C32 | 3 | 226.8 nF | C |  | Unpolarized capacitor
C15 | 1 | 10 uH | C_Small |  | Unpolarized capacitor, small symbol
D1, D2, D3 | 3 | 1N4001 | 1N4001 | Diode_THT:D_DO-41_SOD81_P10.16mm_Horizontal | 50V 1A General Purpose Rectifier Diode, DO-41
IC1, IC2, IC6, IC7, IC10, IC11 | 6 | 1EDN7126GXTMA1 | 1EDN7126GXTMA1 | 1EDN7126GXTMA1 | Gate Drivers INT. POWERSTAGE/DRIVER
IC3, IC8, IC12 | 3 | TMP236AQDBZTQ1 | TMP236AQDBZTQ1 | SOT95P237X112-3N | Board Mount Temperature Sensors Automotive grade, &plusmn;0.5&deg;C analog output temperature sensor with 19.5 mV/&deg;C gain 3-SOT-23 -40 to 125
IC4, IC9, IC13 | 3 | TLI4971A075T5UE0001XUMA1 | TLI4971A075T5UE0001XUMA1 | TLI4971A075T5UE0001XUMA1 | Infineon TLI4971A075T5UE0001XUMA1
IC5 | 1 | SN74HC4851DGVR | SN74HC4851DGVR | SOP40P640X120-16N | 8-Channel Analog Multiplexer/Demultiplexer with Injection-Current Effect Control
J1 | 1 | Screw_Terminal_For_Brushless_Motor | Screw_Terminal_01x03 |  | Generic screw terminal, single row, 01x03, script generated (kicad-library-utils/schlib/autogen/connector/)
Q1, Q2, Q3, Q4, Q5, Q6 | 6 | IGT60R070D1 | IGT60R070D1 | Package_TO_SOT_SMD:Infineon_PG-HSOF-8-3_ThermalVias | 31A Id, 600V Vds, 70mOhm, N-Channel GaN MOSFET, HSOF-8
R1, R2, R3, R4, R8, R9, R10, R11, R12, R13, R14, R15, R16, R17, R18, R19, R23, R24, R25, R26 | 20 | R | R |  | Resistor
R5, R20, R27 | 3 | 4.7 k | R |  | Resistor
R6, R7, R21, R22, R28, R29 | 6 | 1 k | R |  | Resistor
U1 | 1 | AS5048B | AS5048B | Package_SO:TSSOP-14_4.4x5mm_P0.65mm | Magnetic position sensor, 14-bit, PWM output, I2C Interface, TSSOP-14

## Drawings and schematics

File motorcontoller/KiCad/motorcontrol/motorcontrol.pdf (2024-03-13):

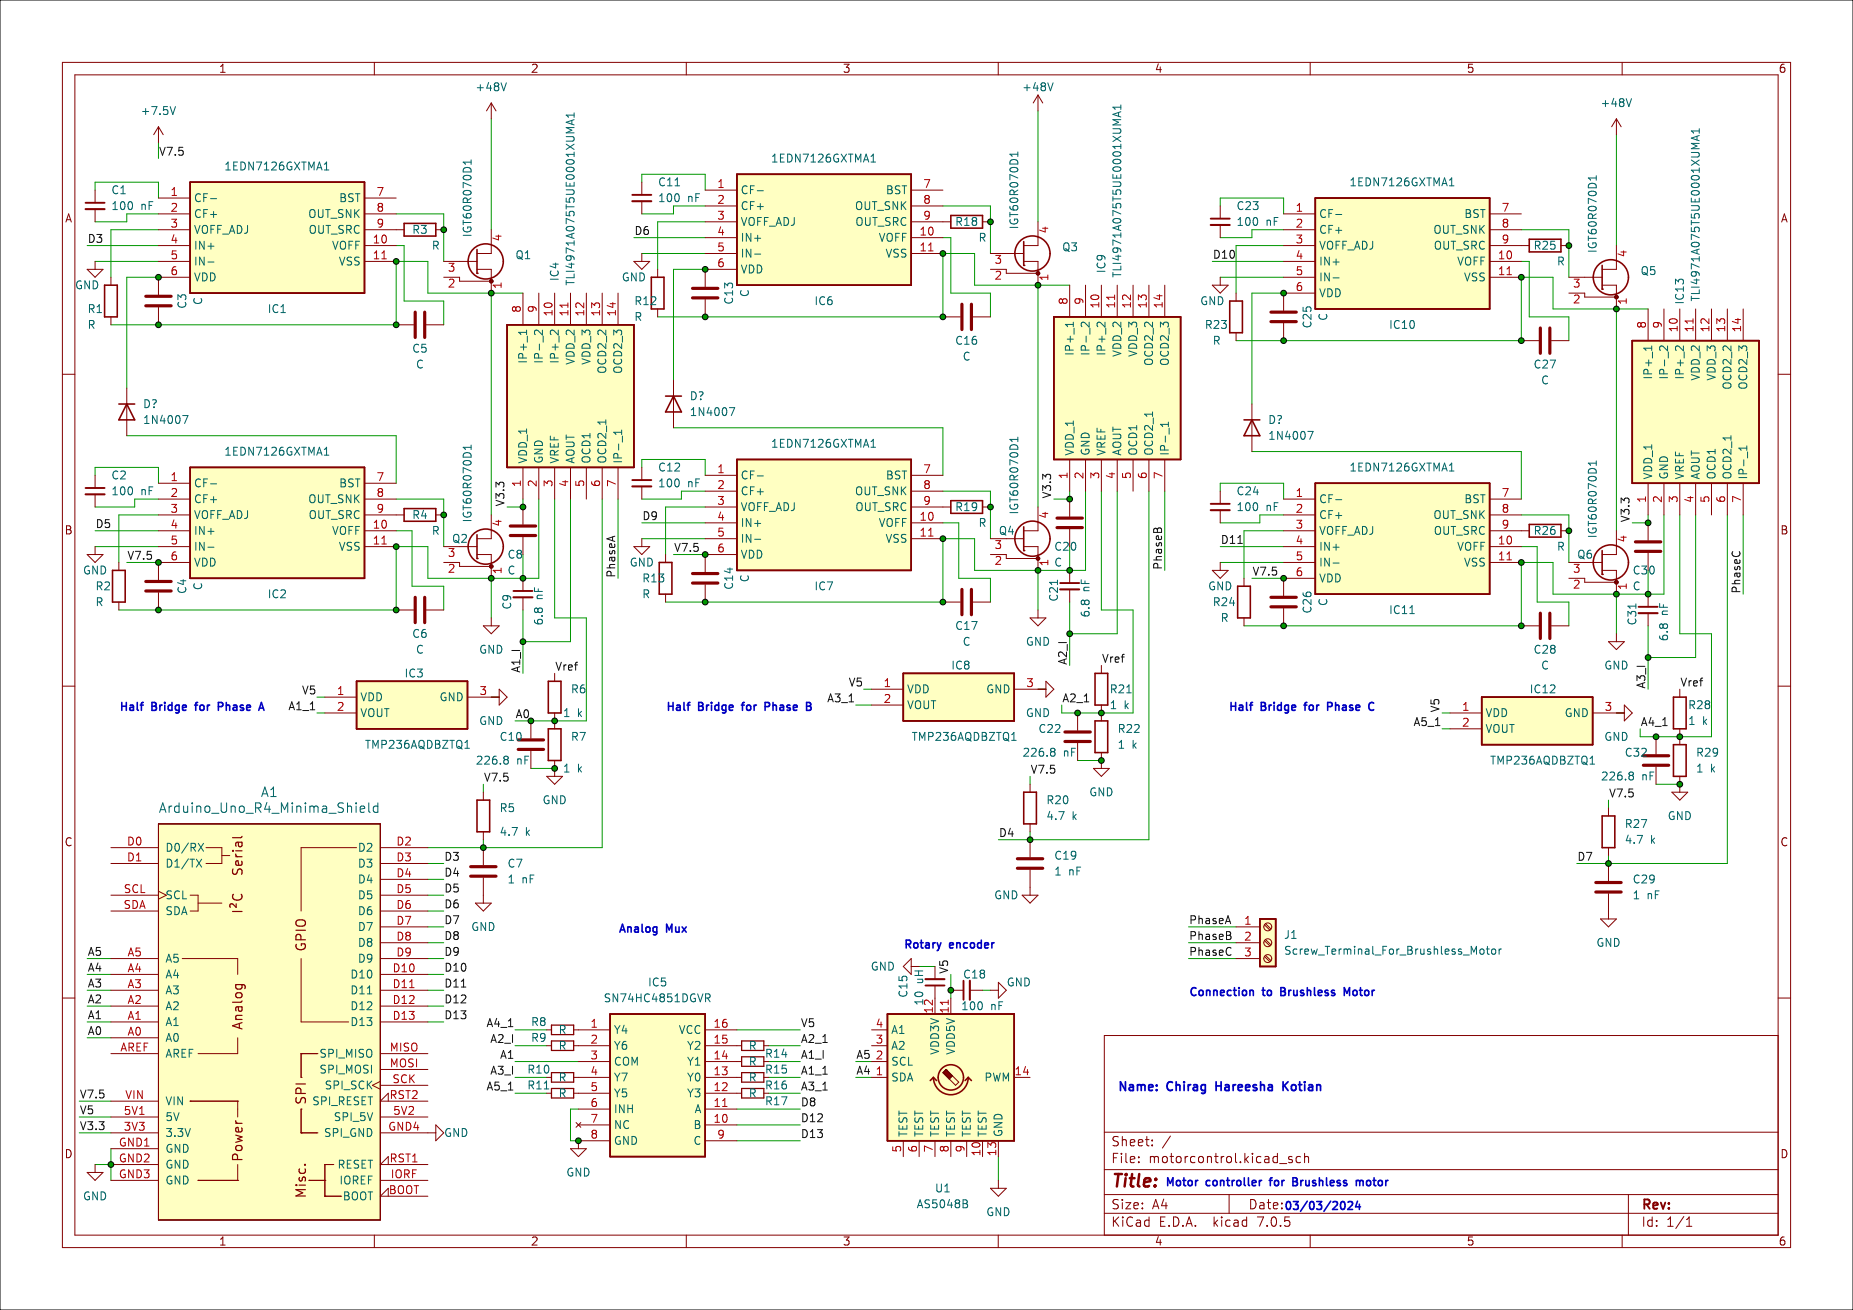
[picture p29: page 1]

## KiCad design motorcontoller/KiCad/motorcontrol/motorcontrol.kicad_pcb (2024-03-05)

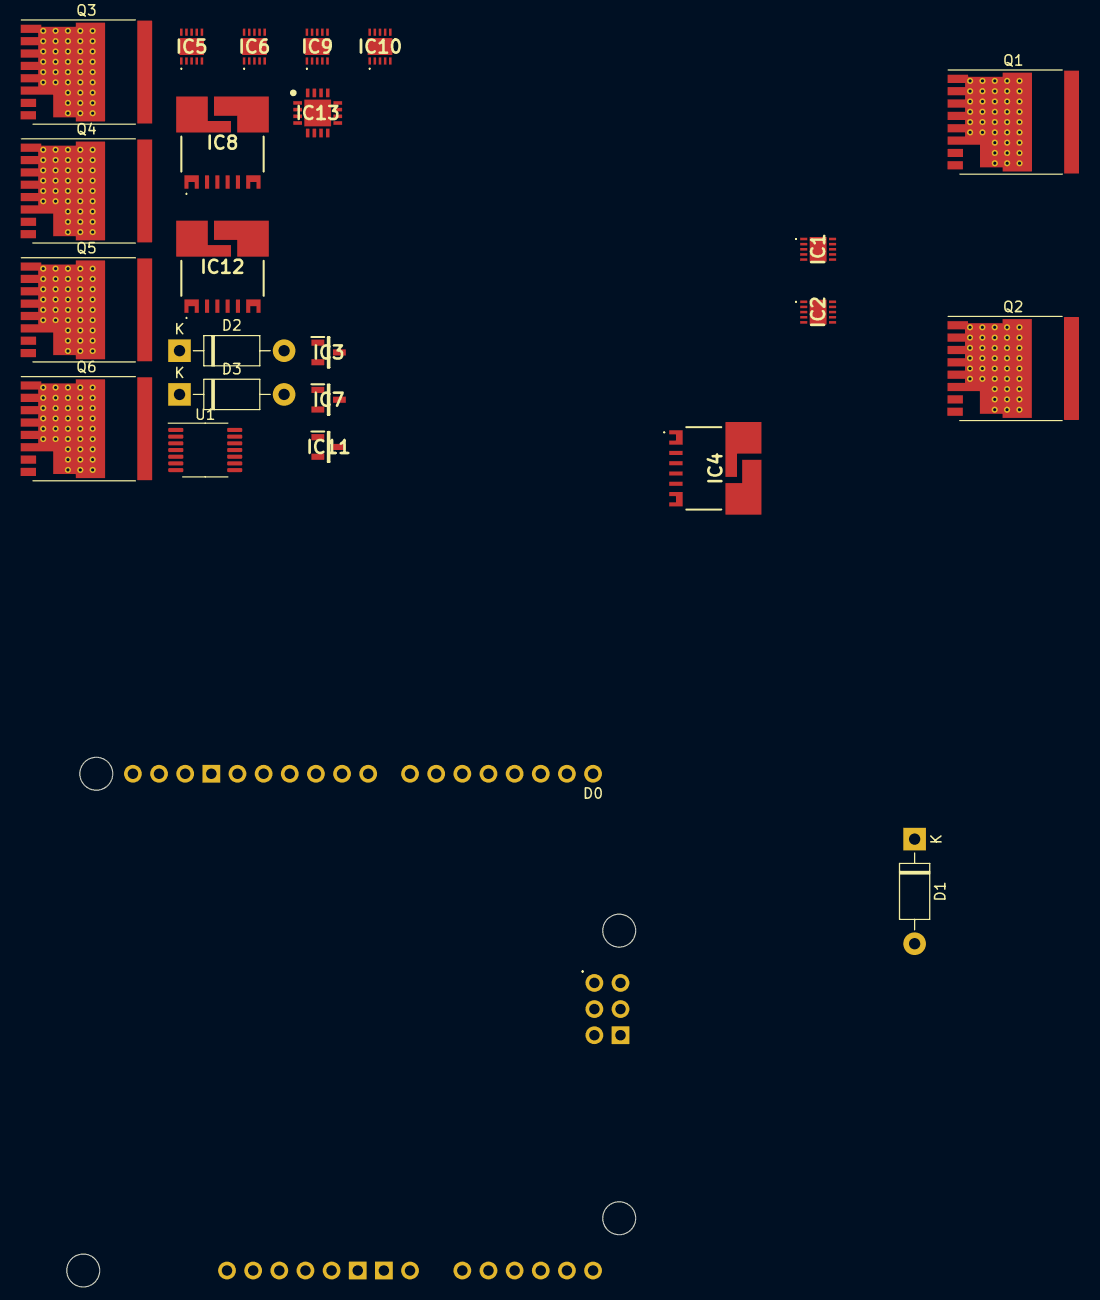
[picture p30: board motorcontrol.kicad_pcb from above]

Board: 2 copper layers, 24 parts (0 on the bottom side), 42 nets, no tracks yet.

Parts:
A2: Arduino_Uno_R4_Minima_Shield
D1, D2, D3: 1N4001; D_DO-41_SOD81_P10.16mm_Horizontal
IC1, IC2, IC5, IC6, IC9, IC10: 1EDN7126GXTMA1
IC3, IC7, IC11: TMP236AQDBZTQ1; SOT95P237X112-3N
IC4, IC8, IC12: TLI4971A075T5UE0001XUMA1
IC13: TMUX6211RUMR; QFN65P400X400X80-17N-D
Q1, Q2, Q3, Q4, Q5, Q6: IGT60R070D1; Infineon_PG-HSOF-8-3_ThermalVias
U1: AS5048B; TSSOP-14_4.4x5mm_P0.65mm

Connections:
+7.5V: A2.VIN, IC2.6 (VDD), IC6.6 (VDD), IC10.6 (VDD)
+48V: Q1.4 (D), Q3.4 (D), Q5.4 (D)
/A0: A2.A0, IC4.3 (VREF)
/A1: A2.A1, IC3.2 (VOUT)
/A2: A2.A2, IC13.1 (S1), IC13.4 (S4), IC13.9 (S3), IC13.12 (S2)
/A2_1: IC8.3 (VREF), IC13.16 (D1)
/A3_1: IC7.2 (VOUT), IC13.13 (D2)
/A4: A2.A4, U1.1 (SDA)
/A4_1: IC12.3 (VREF), IC13.8 (D3)
/A5: A2.A5, U1.2 (SCL)
/A5_1: IC11.2 (VOUT), IC13.5 (D4)
/D1: A2.D1 (D1/TX), IC13.7 (SEL3)
/D3: A2.D3, IC1.4 (IN+)
/D4: A2.D4, IC8.6 (OCD2_1)
/D5: A2.D5, IC2.4 (IN+)
/D6: A2.D6, IC5.4 (IN+)
/D7: A2.D7, IC12.6 (OCD2_1)
/D8: A2.D8, IC13.15 (SEL1)
/D9: A2.D9, IC6.4 (IN+)
/D10: A2.D10, IC9.4 (IN+)
/D11: A2.D11, IC10.4 (IN+)
/D12: A2.D12, IC13.14 (SEL2)
/D13: A2.D13, IC13.6 (SEL4)
/V3.3: A2.3V3 (3.3V), IC4.1 (VDD_1), IC8.1 (VDD_1), IC12.1 (VDD_1)
/V5: A2.5V1 (5V), IC3.1 (VDD), IC7.1 (VDD), IC11.1 (VDD), IC13.11 (VDD), IC13.17 (EP), U1.11 (VDD5V)
GND: A2.GND1 (GND), A2.GND2 (GND), A2.GND3 (GND), A2.GND4 (SPI_GND), IC1.5 (IN-), IC2.5 (IN-), IC2.11 (VSS), IC3.3 (GND), IC4.2 (GND), IC5.5 (IN-), IC6.5 (IN-), IC6.11 (VSS), IC7.3 (GND), IC8.2 (GND), IC9.5 (IN-), IC10.5 (IN-), IC10.11 (VSS), IC11.3 (GND), IC12.2 (GND), IC13.3 (GND), Q2.1 (S), Q4.1 (S), Q6.1 (S), U1.13 (GND)
unnamed: D1.2 (A), IC2.7 (BST)
unnamed: D1.1 (K), IC1.6 (VDD)
unnamed: D2.2 (A), IC6.7 (BST)
unnamed: D2.1 (K), IC5.6 (VDD)
unnamed: D3.2 (A), IC10.7 (BST)
unnamed: D3.1 (K), IC9.6 (VDD)
unnamed: IC1.8 (OUT_SNK), Q1.3 (G)
unnamed: IC1.11 (VSS), IC4.8 (IP+_1), Q1.1 (S), Q2.4 (D)
unnamed: IC2.8 (OUT_SNK), Q2.3 (G)
unnamed: A2.D2, IC4.6 (OCD2_1)
unnamed: IC5.8 (OUT_SNK), Q3.3 (G)
unnamed: IC5.11 (VSS), IC8.8 (IP+_1), Q3.1 (S), Q4.4 (D)
unnamed: IC6.8 (OUT_SNK), Q4.3 (G)
unnamed: IC9.8 (OUT_SNK), Q5.3 (G)
unnamed: IC10.8 (OUT_SNK), Q6.3 (G)
unnamed: IC9.11 (VSS), IC12.8 (IP+_1), Q5.1 (S), Q6.4 (D)
